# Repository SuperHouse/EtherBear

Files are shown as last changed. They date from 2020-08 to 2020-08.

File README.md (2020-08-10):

SuperHouse EtherBear
=====================

The EtherBear is an Arduino compatible development board for the
ATmega1284P microcontroller, with a Wiznet W6100 Ethernet interface and
Power-over-Ethernet support.

The W6100 provides both IPv4 and IPv6 support.

EtherUNO

Features:

 * LEDs visible on the edge
 * USB-C Connector
 * I2C MAC address ROM
 * Overlay guide where you need it (both top and bottom)
 * D13 pin works for everything
 * RX pin biased
 * Mounting holes

More information is available at:

  https://www.superhouse.tv/etherbear

Hardware
--------
The "Hardware" directory contains the PCB design as an EAGLE project.
EAGLE PCB design software is available from Autodesk free for
non-commercial use.

Credits
-------
 * Jonathan Oxer <jon@oxer.com.au>

The EtherBear is based on the EtherUNO, which in turn is based on the
EtherTen, which was designed by Jonathan Oxer and Marc Alexander.

License
-------
Copyright 2020 SuperHouse Automation Pty Ltd  www.superhouse.tv  

The hardware portion of this project is licensed under the TAPR Open
Hardware License (www.tapr.org/OHL). The "license" folder within this
repository contains a copy of this license in plain text format.

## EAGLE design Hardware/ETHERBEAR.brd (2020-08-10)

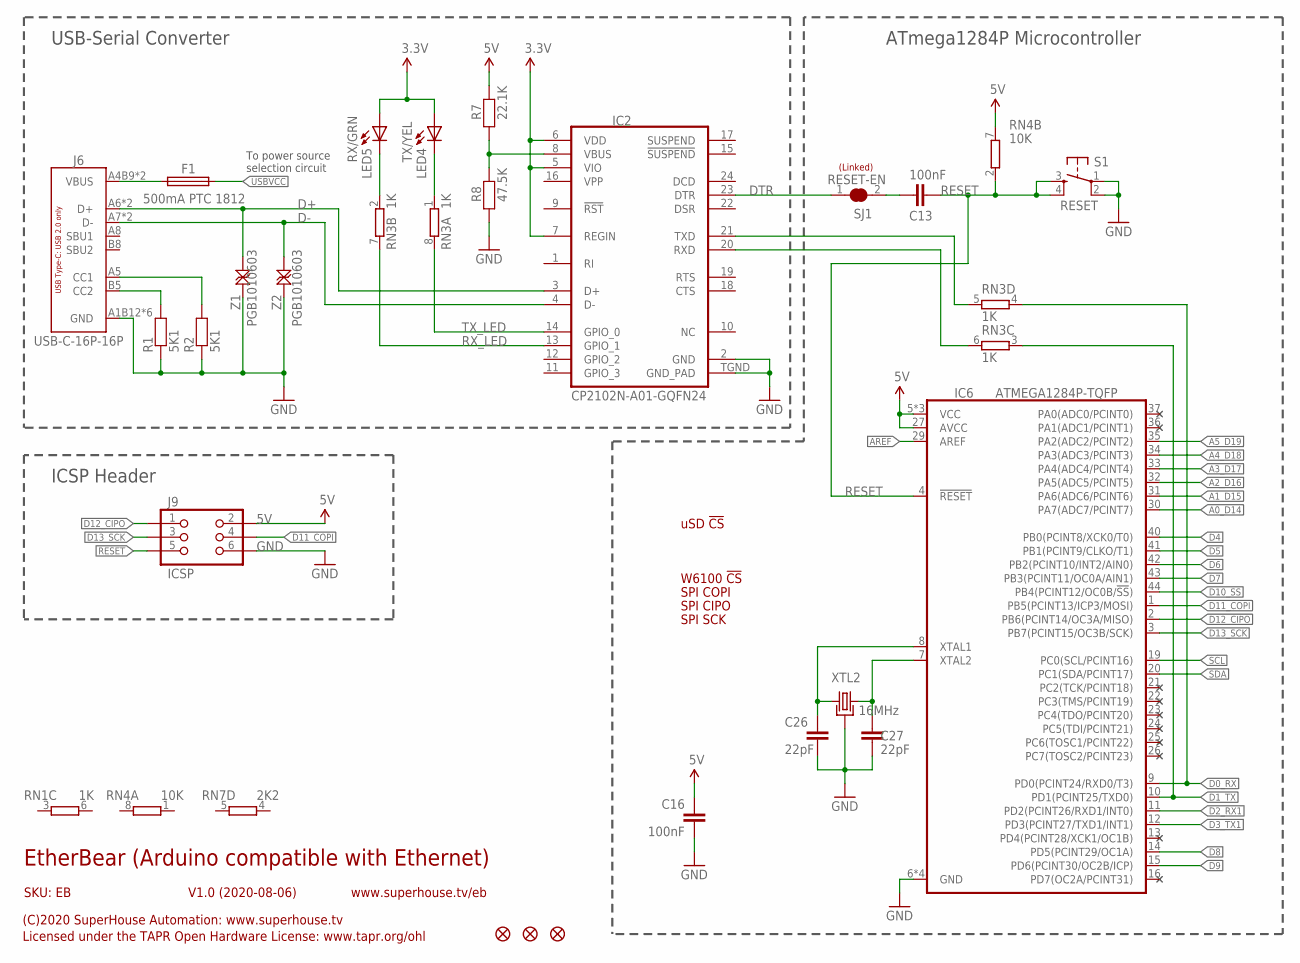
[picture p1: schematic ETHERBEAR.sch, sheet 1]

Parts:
C13, C16: 100nF; C0603
C26, C27: 22pF; C0603
F1: 500mA PTC 1812; 1812
FID1, FID2, FID3: FIDUCIAL1X2.5; FIDUCIAL-1X2.5
IC2: CP2102N-A01-GQFN24; QFN-24
IC6: ATMEGA1284P-TQFP; TQFP44
J6: USB-C-16P-16P; USB-C-16P
J9: ICSP; 2X03-ICSP
LED4: TX/YEL; LED-0603
LED5: RX/GRN; LED-0603
R1, R2: 5K1; R0603
R7: 22.1K; R0603
R8: 47.5K; R0603
RN1, RN3: 1K; CAY16
RN4: 10K; CAY16
RN7: 2K2; CAY16
S1: RESET; TACTILE_SMT-6MM
SJ1: RESET-EN; SJC
XTL2: 16MHz; CRYSTAL-SMD-3X2
Z1, Z2: PGB1010603; TVS0603

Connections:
3.3V: IC2.5 (VIO), IC2.6 (VDD), IC2.7 (REGIN), LED4.A, LED5.A; also elsewhere on the board
5V: C16.1, IC6.5 (VCC), IC6.17 (VCC), IC6.27 (AVCC), IC6.28 (VCC), J9.2, R7.2, RN4.7 (2); also elsewhere on the board
A0_D14: IC6.30 (PA7(ADC7/PCINT7)); also elsewhere on the board
A1_D15: IC6.31 (PA6(ADC6/PCINT6)); also elsewhere on the board
A2_D16: IC6.32 (PA5(ADC5/PCINT5)); also elsewhere on the board
A3_D17: IC6.33 (PA4(ADC4/PCINT4)); also elsewhere on the board
A4_D18: IC6.34 (PA3(ADC3/PCINT3)); also elsewhere on the board
A5_D19: IC6.35 (PA2(ADC2/PCINT2)); also elsewhere on the board
AREF: IC6.29 (AREF); also elsewhere on the board
D0_RX: IC6.9 (PD0(PCINT24/RXD0/T3)), RN3.4 (1); also elsewhere on the board
D1_TX: IC6.10 (PD1(PCINT25/TXD0)), RN3.3 (1); also elsewhere on the board
D2_RX1: IC6.11 (PD2(PCINT26/RXD1/INT0)); also elsewhere on the board
D3_TX1: IC6.12 (PD3(PCINT27/TXD1/INT1)); also elsewhere on the board
D4: IC6.40 (PB0(PCINT8/XCK0/T0)); also elsewhere on the board
D5: IC6.41 (PB1(PCINT9/CLKO/T1)); also elsewhere on the board
D6: IC6.42 (PB2(PCINT10/INT2/AIN0)); also elsewhere on the board
D7: IC6.43 (PB3(PCINT11/OC0A/AIN1)); also elsewhere on the board
D8: IC6.14 (PD5(PCINT29/OC1A)); also elsewhere on the board
D9: IC6.15 (PD6(PCINT30/OC2B/ICP)); also elsewhere on the board
D10_SS: IC6.44 (PB4(PCINT12/OC0B/!SS!))
D11_COPI: IC6.1 (PB5(PCINT13/ICP3/MOSI)), J9.4; also elsewhere on the board
D12_CIPO: IC6.2 (PB6(PCINT14/OC3A/MISO)), J9.1; also elsewhere on the board
D13_SCK: IC6.3 (PB7(PCINT15/OC3B/SCK)), J9.3; also elsewhere on the board
D+: IC2.3 (D+), J6.A6 (D+), J6.B6 (D+), Z1.1
D-: IC2.4 (D-), J6.A7 (D-), J6.B7 (D-), Z2.1
DTR: IC2.23 (DTR), SJ1.1
GND: C16.2, C26.1, C27.1, IC2.2 (GND), IC2.TGND (GND_PAD), IC6.6 (GND), IC6.18 (GND), IC6.38 (GND), IC6.39 (GND), J6.A1B12 (GND), J6.A12B1 (GND), J6.FIX1 (GND), J6.FIX2 (GND), J6.FIX3 (GND), J6.FIX4 (GND), J9.6, R1.1, R2.1, R8.1, S1.1, S1.2, XTL2.2 (GND), XTL2.4 (GND), Z1.2, Z2.2; also elsewhere on the board
unnamed: C26.2, IC6.8 (XTAL1), XTL2.1
unnamed: C13.1, SJ1.2
unnamed: C27.2, IC6.7 (XTAL2), XTL2.3 (2)
unnamed: J6.B5 (CC2), R1.2
unnamed: LED5.C, RN3.2 (1)
unnamed: LED4.C, RN3.1
unnamed: J6.A5 (CC1), R2.2
unnamed: IC2.8 (VBUS), R7.1, R8.2
unnamed: F1.1, J6.A4B9 (VBUS), J6.A9B4 (VBUS)
RESET: C13.2, IC6.4 (!RESET), J9.5, RN4.2 (1), S1.3, S1.4; also elsewhere on the board
RX_LED: IC2.13 (GPIO_1), RN3.7 (2)
SCL: IC6.19 (PC0(SCL/PCINT16)); also elsewhere on the board
SDA: IC6.20 (PC1(SDA/PCINT17)); also elsewhere on the board
TX_LED: IC2.14 (GPIO_0), RN3.8 (2)
USBRXD: IC2.21 (TXD), RN3.5 (2)
USBTXD: IC2.20 (RXD), RN3.6 (2)
USBVCC: F1.2; also elsewhere on the board

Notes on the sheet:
(Linked)
EtherBear (Arduino compatible with Ethernet)
SKU: EB
(C)2020 SuperHouse Automation: www.superhouse.tv
Licensed under the TAPR Open Hardware License: www.tapr.org/ohl
www.superhouse.tv/eb
V1.0 (2020-08-06)
USB-Serial Converter
ATmega1284P Microcontroller
ICSP Header
To power source selection circuit
uSD !CS
W6100 !CS
SPI COPI
SPI CIPO
SPI SCK

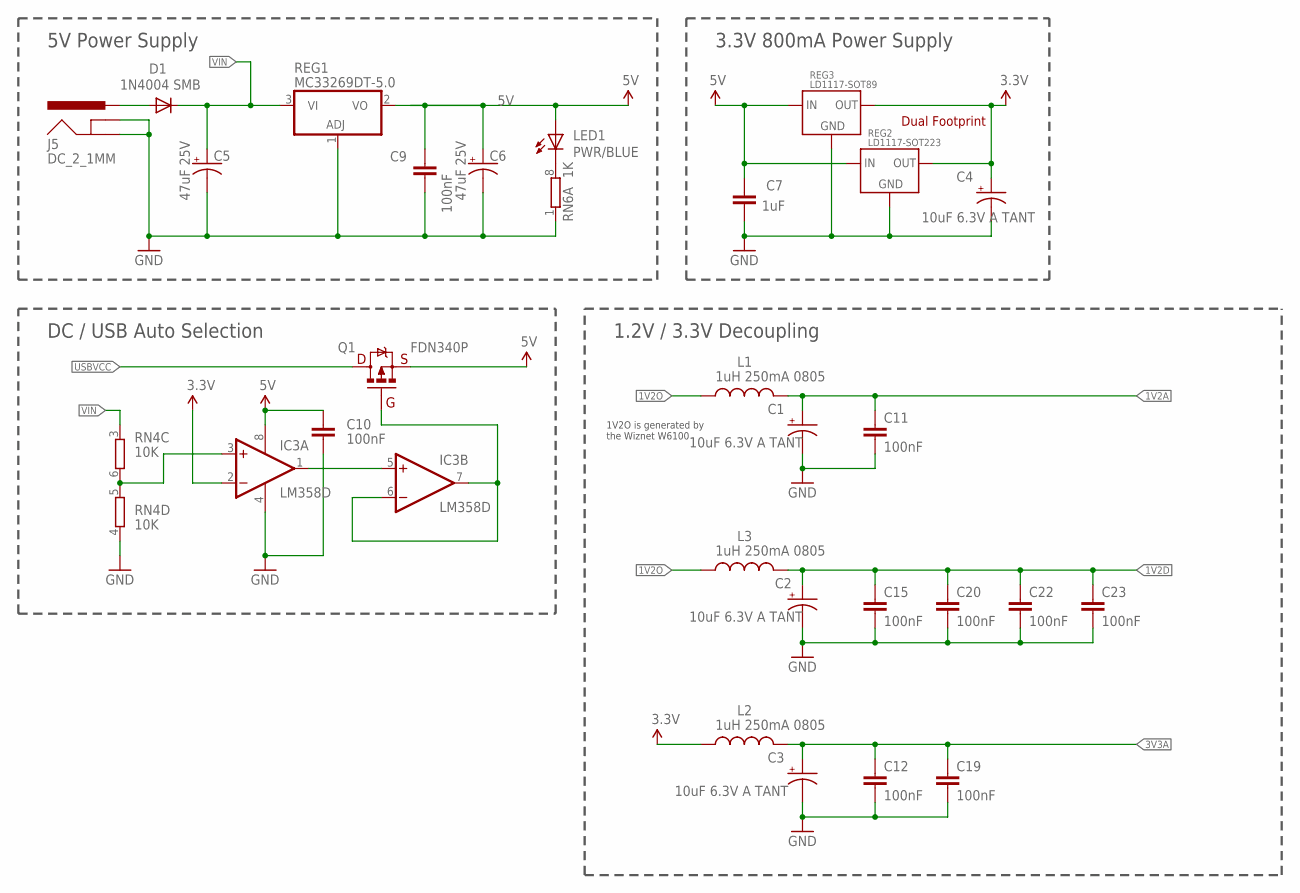
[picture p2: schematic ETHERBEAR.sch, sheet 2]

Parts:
C1, C2, C3, C4: 10uF 6.3V A TANT; EIA3216
C5, C6: 47uF 25V; PANASONIC_D
C7: 1uF; C0603
C9, C10, C11, C12, C15, C19, C20, C22, C23: 100nF; C0603
D1: 1N4004 SMB; SMA-DIODE
IC3: LM358D; SO08
J5: DC_2_1MM; POWER_JACK_SLOTS
L1, L2, L3: 1uH 250mA 0805; 0805-LARGE
LED1: PWR/BLUE; LED-0603
Q1: FDN340P; SOT23
REG1: MC33269DT-5.0; DPACK
REG2: LD1117-SOT223; SOT-223
REG3: LD1117-SOT89; SOT89
RN4: 10K; CAY16
RN6: 1K; CAY16

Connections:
1V2A: C1.A (+), C11.1, L1.2; also elsewhere on the board
1V2D: C2.A (+), C15.1, C20.1, C22.1, C23.1, L3.2; also elsewhere on the board
1V2O: L1.1, L3.1; also elsewhere on the board
3.3V: C4.A (+), IC3.2 (-IN), L2.1, REG2.2 (OUT), REG2.4 (OUT), REG3.2 (OUT), REG3.4 (OUT); also elsewhere on the board
3V3A: C3.A (+), C12.1, C19.1, L2.2; also elsewhere on the board
5V: C6.+, C7.1, C9.1, C10.1, IC3.8 (V+), LED1.A, Q1.2 (S), REG1.2 (VO), REG2.3 (IN), REG3.3 (IN); also elsewhere on the board
GND: C1.C (-), C2.C (-), C3.C (-), C4.C (-), C5.-, C6.-, C7.2, C9.2, C10.2, C11.2, C12.2, C15.2, C19.2, C20.2, C22.2, C23.2, IC3.4 (V-), J5.GND, J5.GNDBREAK, REG1.1 (ADJ), REG2.1 (GND), REG3.1 (GND), RN4.4 (1), RN6.1; also elsewhere on the board
unnamed: IC3.3 (+IN), RN4.5 (2), RN4.6 (2)
unnamed: LED1.C, RN6.8 (2)
unnamed: IC3.6 (-IN), IC3.7 (OUT), Q1.1 (G)
unnamed: IC3.1 (OUT), IC3.5 (+IN)
unnamed: D1.A, J5.PWR
USBVCC: Q1.3 (D); also elsewhere on the board
VIN: C5.+, D1.C, REG1.3 (VI), RN4.3 (1); also elsewhere on the board

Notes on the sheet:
Dual Footprint
1V2O is generated by the Wiznet W6100
1.2V / 3.3V Decoupling
3.3V 800mA Power Supply
5V Power Supply
DC / USB Auto Selection

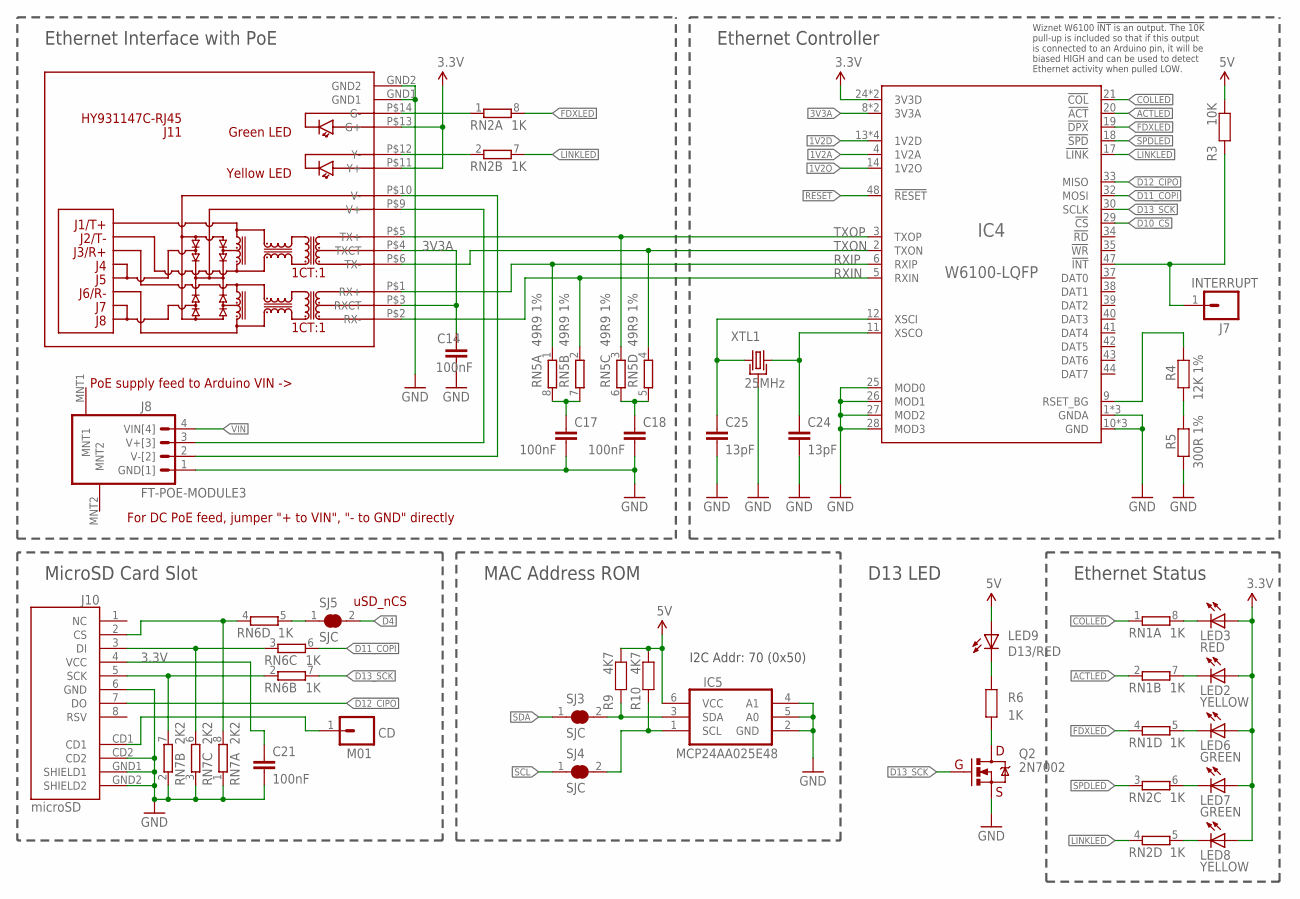
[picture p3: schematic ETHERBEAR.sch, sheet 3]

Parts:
C14, C17, C18, C21: 100nF; C0603
C24, C25: 13pF; C0603
CD: M01; 1X01
IC4: W6100-LQFP; LQFP48
IC5: MCP24AA025E48; SOT23-6
J7: INTERRUPT; 1X01
J8: FT-POE-MODULE3; FT-POE-MODULE-NOLABEL
J10: microSD; MICRO-SD-SOCKET-PP
J11: HY931147C-RJ45; HY931147C
LED2, LED8: YELLOW; LED-0603
LED3: RED; LED-0603
LED6, LED7: GREEN; LED-0603
LED9: D13/RED; LED-0603
Q2: 2N7002; SOT23-3
R3: 10K; R0603
R4: 12K 1%; R0603
R5: 300R 1%; R0603
R6: 1K; R0603
R9, R10: 4K7; R0603
RN1, RN2, RN6: 1K; CAY16
RN5: 49R9 1%; CAY16
RN7: 2K2; CAY16
SJ3, SJ4, SJ5: SJC
XTL1: 25MHz; CRYSTAL-SMD-3X2

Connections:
1V2A: IC4.4 (1V2A); also elsewhere on the board
1V2D: IC4.13 (1V2D), IC4.22 (1V2D), IC4.31 (1V2D), IC4.45 (1V2D); also elsewhere on the board
1V2O: IC4.14 (1V2O); also elsewhere on the board
3.3V: C21.1, IC4.24 (3V3D), IC4.36 (3V3D), J10.4 (VCC), J11.P$11 (Y+), J11.P$13 (G+), LED2.A, LED3.A, LED6.A, LED7.A, LED8.A; also elsewhere on the board
3V3A: C14.1, IC4.8 (3V3A), IC4.15 (3V3A), J11.P$3 (RXCT), J11.P$4 (TXCT); also elsewhere on the board
5V: IC5.6 (VCC), LED9.A, R3.1, R9.1, R10.1; also elsewhere on the board
ACTLED: IC4.20 (!ACT), RN1.2 (1)
COLLED: IC4.21 (!COL), RN1.1
D4: SJ5.2; also elsewhere on the board
D10_CS: IC4.29 (!CS); also elsewhere on the board
D11_COPI: IC4.32 (MOSI), RN6.6 (2); also elsewhere on the board
D12_CIPO: IC4.33 (MISO), J10.7 (DO); also elsewhere on the board
D13_SCK: IC4.30 (SCLK), Q2.1 (G), RN6.7 (2); also elsewhere on the board
FDXLED: IC4.19 (!DPX), RN1.4 (1), RN2.8 (2)
GND: C14.2, C17.2, C18.2, C21.2, C24.2, C25.2, IC4.1 (GNDA), IC4.7 (GNDA), IC4.10 (GND), IC4.16 (GNDA), IC4.23 (GND), IC4.25 (MOD0), IC4.26 (MOD1), IC4.27 (MOD2), IC4.28 (MOD3), IC4.46 (GND), IC5.2 (GND), IC5.4 (A1), IC5.5 (A0), J8.1 (GND[1]), J10.6 (GND), J10.CD2, J10.GND1 (SHIELD1), J10.GND2 (SHIELD2), J11.GND1, J11.GND2, Q2.2 (S), R5.2, RN7.1, RN7.2 (1), RN7.3 (1), XTL1.2 (GND), XTL1.4 (GND); also elsewhere on the board
LINKLED: IC4.17 (!LINK), RN2.4 (1), RN2.7 (2)
unnamed: C18.1, RN5.5 (2), RN5.6 (2)
unnamed: LED9.C, R6.2
unnamed: IC5.1 (SCL), R10.2, SJ4.2
unnamed: Q2.3 (D), R6.1
unnamed: LED3.C, RN1.8 (2)
unnamed: IC4.47 (!INT), J7.1, R3.2
unnamed: J10.2 (CS), RN6.4 (1), RN7.8 (2)
unnamed: CD.1, J10.CD1
unnamed: J10.5 (SCK), RN6.2 (1), RN7.7 (2)
unnamed: J10.3 (DI), RN6.3 (1), RN7.6 (2)
unnamed: LED7.C, RN2.6 (2)
unnamed: RN6.5 (2), SJ5.1
unnamed: LED8.C, RN2.5 (2)
unnamed: IC5.3 (SDA), R9.2, SJ3.2
unnamed: C24.1, IC4.11 (XSCO), XTL1.3 (2)
unnamed: C25.1, IC4.12 (XSCI), XTL1.1
unnamed: R4.2, R5.1
unnamed: IC4.9 (RSET_BG), R4.1
unnamed: J11.P$14 (G-), RN2.1
unnamed: J8.3 (V+[3]), J11.P$9 (V+)
unnamed: J8.2 (V-[2]), J11.P$10 (V-)
unnamed: C17.1, RN5.7 (2), RN5.8 (2)
unnamed: LED6.C, RN1.5 (2)
unnamed: LED2.C, RN1.7 (2)
unnamed: J11.P$12 (Y-), RN2.2 (1)
RESET: IC4.48 (!RESET); also elsewhere on the board
RXIN: IC4.5 (RXIN), J11.P$2 (RX-), RN5.2 (1)
RXIP: IC4.6 (RXIP), J11.P$1 (RX+), RN5.1
SCL: SJ4.1; also elsewhere on the board
SDA: SJ3.1; also elsewhere on the board
SPDLED: IC4.18 (!SPD), RN2.3 (1)
TXON: IC4.2 (TXON), J11.P$6 (TX-), RN5.4 (1)
TXOP: IC4.3 (TXOP), J11.P$5 (TX+), RN5.3 (1)
VIN: J8.4 (VIN[4]); also elsewhere on the board

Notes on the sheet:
PoE supply feed to Arduino VIN ->
For DC PoE feed, jumper "+ to VIN", "- to GND" directly
I2C Addr: 70 (0x50)
uSD_nCS
Ethernet Interface with PoE
Ethernet Controller
MAC Address ROM
MicroSD Card Slot
Ethernet Status
Wiznet W6100 !INT is an output. The 10K pull-up is included so that if this output is connected to an Arduino pin, it will be biased HIGH and can be used to detect Ethernet activity when pulled LOW.
D13 LED

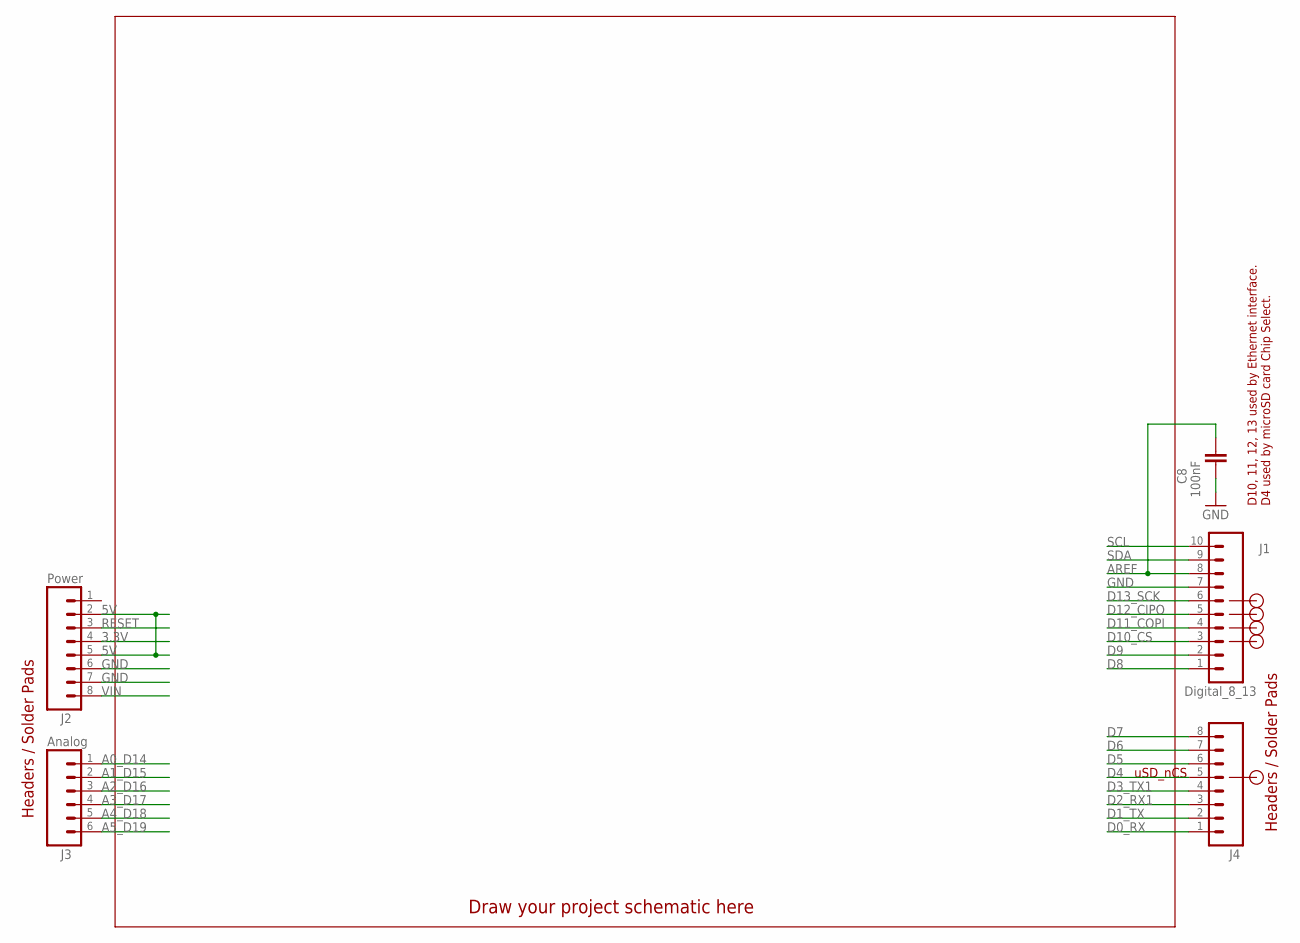
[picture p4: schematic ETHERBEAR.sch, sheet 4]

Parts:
C8: 100nF; C0603
J1: Digital_8_13; 1X10-S
J2: Power; 1X08-S
J3: Analog; 1X06-S
J4: Digital_0_7; 1X08-S

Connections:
3.3V: J2.4; also elsewhere on the board
5V: J2.2, J2.5; also elsewhere on the board
A0_D14: J3.1; also elsewhere on the board
A1_D15: J3.2; also elsewhere on the board
A2_D16: J3.3; also elsewhere on the board
A3_D17: J3.4; also elsewhere on the board
A4_D18: J3.5; also elsewhere on the board
A5_D19: J3.6; also elsewhere on the board
AREF: C8.1, J1.8; also elsewhere on the board
D0_RX: J4.1; also elsewhere on the board
D1_TX: J4.2; also elsewhere on the board
D2_RX1: J4.3; also elsewhere on the board
D3_TX1: J4.4; also elsewhere on the board
D4: J4.5; also elsewhere on the board
D5: J4.6; also elsewhere on the board
D6: J4.7; also elsewhere on the board
D7: J4.8; also elsewhere on the board
D8: J1.1; also elsewhere on the board
D9: J1.2; also elsewhere on the board
D10_CS: J1.3; also elsewhere on the board
D11_COPI: J1.4; also elsewhere on the board
D12_CIPO: J1.5; also elsewhere on the board
D13_SCK: J1.6; also elsewhere on the board
GND: C8.2, J1.7, J2.6, J2.7; also elsewhere on the board
RESET: J2.3; also elsewhere on the board
SCL: J1.10; also elsewhere on the board
SDA: J1.9; also elsewhere on the board
VIN: J2.8; also elsewhere on the board

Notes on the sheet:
Headers / Solder Pads
Draw your project schematic here
D10, 11, 12, 13 used by Ethernet interface.
uSD_nCS
D4 used by microSD card Chip Select.

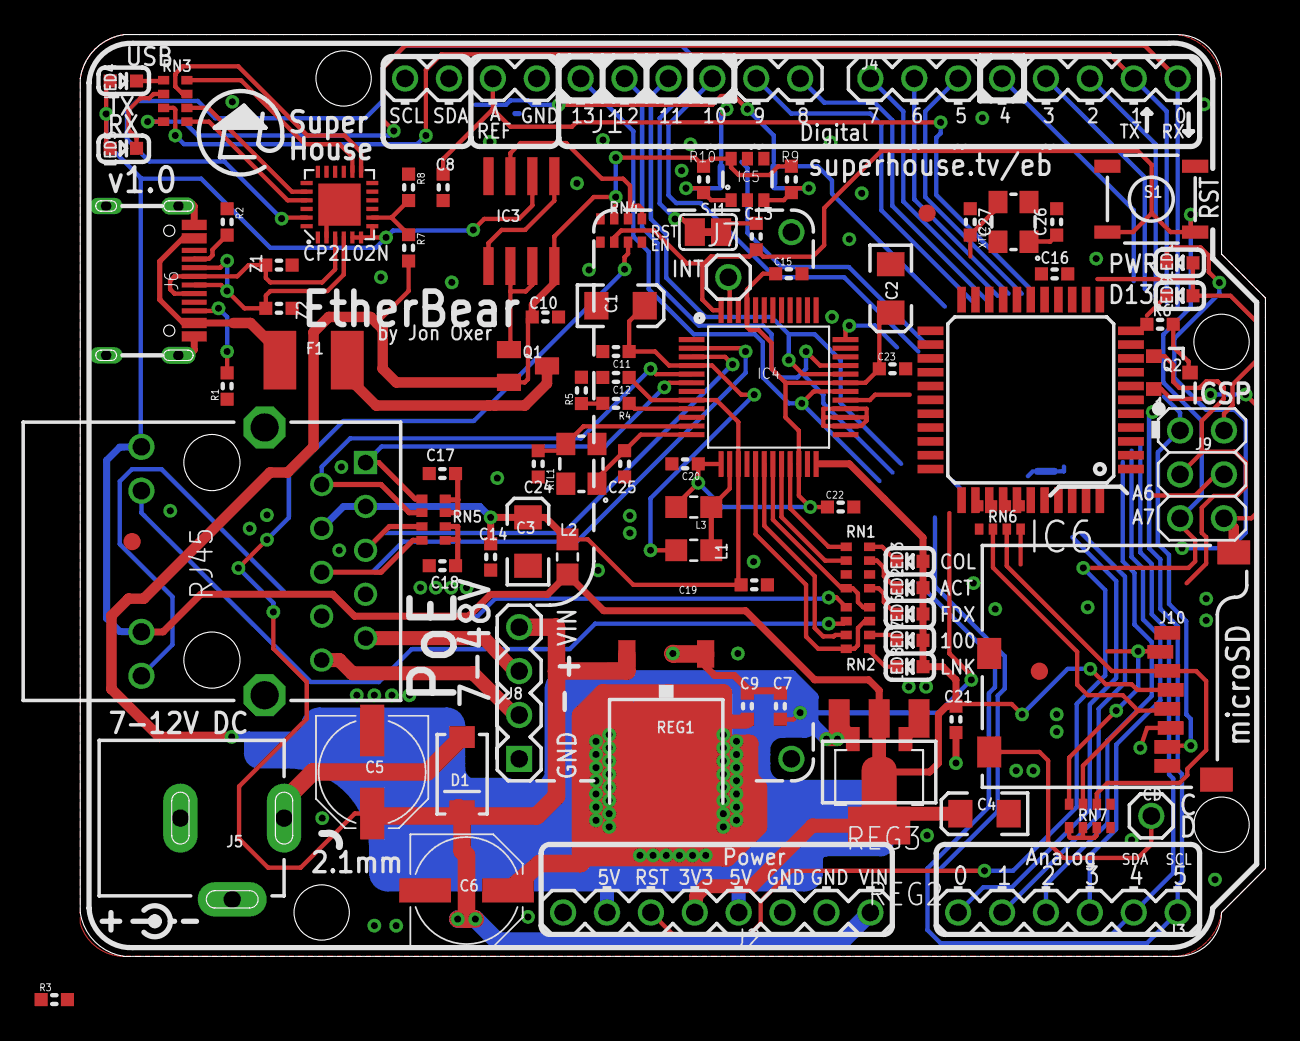
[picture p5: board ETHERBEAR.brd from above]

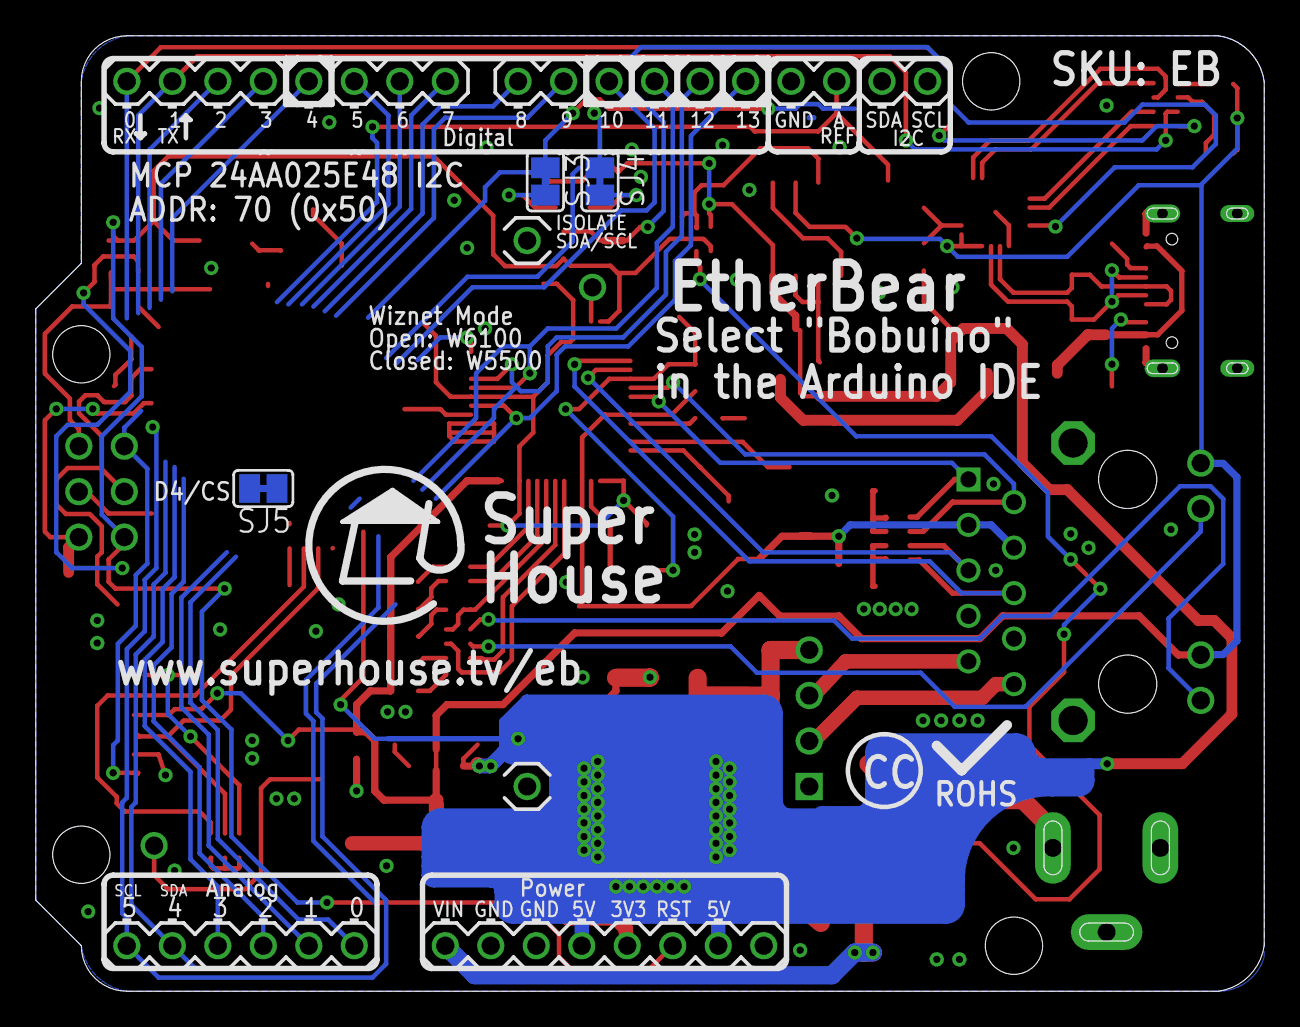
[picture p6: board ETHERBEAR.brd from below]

Board: 2 copper layers, 68.6 x 53.3 mm, 92 parts (3 on the bottom side), 88 nets.

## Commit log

2020-08-10 Added schematics for other W6100 boards
2020-08-10 Schematic changes for ATmega1284P
    [ETHERBEAR.brd, ETHERBEAR.sch]
